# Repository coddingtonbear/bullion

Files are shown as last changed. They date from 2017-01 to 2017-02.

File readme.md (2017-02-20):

# USB & SPI Interface for FS9721-based Multimeter (Bullion)



Do you have a cheap Chinese multimeter using the FS9721 chipset and
want to add an easy-to-use USB interface to it?  Or, do you have an
arduino project in mind where you might want to collect measurements
from your multimeter?  This project can help you do both of those things.

## Compatible Multimeters

Any multimeter using the FS9721 chipset is compatible, but you may have
to adapt the hardware design herein if your multimeter does not have a
3.5mm stereo jack labeled "RS232".

Known-compatible multimeters include:

* **RECOMMENDED** [TekPower TP4000ZC](https://www.amazon.com/Tekpower-TP4000ZC-Interfaced-Multimeter-Computer/dp/B000OPDFLM)
    * Also available as the Digitek DT-4000ZC.
    * Includes a 3.5mm RS232 port.
* [Mastech V&A 18B](https://www.amazon.com/Manual-Ranging-Digital-Multimeter-Interface/dp/B000LQONYM)
    * Does have an external RS232 port, but it is not compatible with the
      hardware files you'll find herein.  You will have to improvise.
* [UNI-T UT60E](https://www.amazon.com/UNI-T-UT60E-Precise-Light-Weight/dp/B0152OJAWC)
    * Does have an external RS232 port, but it is not compatible with the
      hardware files you'll find herein.  You will have to improvise.

## Interfaces

### USB

* Baud Rate: 2400

When connected to your PC, the device will appear as an additional serial
port (may require installation of a driver for the CH340G USB UART
chip).

By default, the raw output from the Multimeter will be displayed
as new multimeter data is received in a way identical to that of what the
built-in serial port would output were you to connect it directly to your
computer, but you can select a variety of output formats using the below
commands.

#### Commands

Commands are sent in the format `COMMAND=VALUE` followed by a single
newline character.

* Command ``output``:
    * Value ``raw`` (*default*): Display raw bytes received from multimeter.
    * Value ``value``: Display actual value scaled to base unit.
    * Value ``displayed``: Display displayed value.  Note that this is
      not scaled to the base unit.  Use the ``unit`` command below to
      determine magnitude.
    * Value ``none``: Disable output.
* Command ``units``:
    * Value ``0`` (*default*): Do not print unit.
    * Value ``1``: Print unit.  If the value is not scaled to the base
      unit, this may include an SI magnitude prefix ('u', 'n, 'm', 'k', 'M').

**Note**: *Command output is not displayed until you press <ENTER>*

For example; to display units in the format they are displayed on the screen,
you could send the following two commands:

```
output=displayed
units=1
```

and you would, assuming you were measuring a voltage source, receive responses like:

```
1.244 mV
1.239 mV
```

But, if you wanted to output values scaled to their base unit so programs
consuming these values wouldn't need to worry about the SI magnitude, you
could instead send the following commands:

```
output=value
units=1
```

and you'd receive the following values:

```
0.001244 V
0.001239 V
```

You could even turn off unit display if you were not concerned about
identifying what mode the multimeter was in while the returned measurement
was taking place (note, though, that `units=0` is the default state, so
you need not send that command if you have not already enabled unit display):

```
output=value
units=0
```

and then you'd receive very easy-to-parse values:

```
0.001244
0.001239
```

### SPI

Every SPI transaction is a single 8-bit command ID, followed by a
32-bit response.

The following commands are implemented:

* `0x01`: Return multimeter measurement as IEEE 754 floating point value; this
  value is scaled to the appropriate base unit for the mode in which the
  multimeter is currently operating..
* `0x02`: Return multimeter display as IEEE 754 floating point value.
  Note that this value is not scaled to handle displayed SI magnitudes!
* `0x10`: Return current display flags as bits in this order:
  * 31:
  * 30: Sign
  * 29: Low Battery
  * 28: Hold
  * 27: Rel
  * 26: Beep
  * 25: Sign (?)
  * **24**: RS232
  * 23: AUTO
  * 22: 
  * 21: 
  * 20: M (mega)
  * 19: k (kilo)
  * 18: m (milli)
  * 17: n (nano)
  * **16**: µ (micro)
  * 15: C2C1 00 (?)
  * 14: C2C1 01 (?)
  * 13: C2C1 10 (?)
  * 12: C2C1 11 (?)
  * 11:
  * 10: Diode
  * 09: DC
  * **08**: AC
  * 07:
  * 06:
  * 05: %
  * 04: Hz
  * 03: V
  * 02: A
  * 01: F
  * 00: Ω

#### SPI Troubleshooting

The device itself operates as an SPI slave, and it's rather difficult to
keep up with fast SPI speeds with just a 12Mhz clock, so if you have unreliable
results, try slowing down your SPI bus speed -- it's not like you're
going to ever be able to get more than a few measurements/second
anyway given that the multimeter itself only measures 2-3x second.

#### Arduino Example

```c
#include <SPI.h>

#define MM_PIN 9

void setup() {
  digitalWrite(MM_PIN, HIGH);
  pinMode(MM_PIN, OUTPUT);
  pinMode(MISO, INPUT);
  pinMode(MOSI, OUTPUT);
  pinMode(SCK, OUTPUT);
  SPI.begin();
  SPI.beginTransaction(SPISettings(1000, MSBFIRST, SPI_MODE0));

  Serial.begin(9600);
}

void loop() {
  union {
      float measurement;
      unsigned char bytes[4];
  } floatMeasurement;

  digitalWrite(MM_PIN, LOW);

  // Let's get the current measurement
  SPI.transfer(0x01);
  for(uint8_t i = 0; i < 4; i++) {
    floatMeasurement.bytes[i] = SPI.transfer(i);
  }
  Serial.println(floatMeasurement.measurement, 7);
  digitalWrite(MM_PIN, HIGH);

  delay(500);

  // Now let's print the current flags
  digitalWrite(MM_PIN, LOW);
  SPI.transfer(0x10);
  for(uint8_t i = 0; i < 4; i++) {
    Serial.println(SPI.transfer(i), BIN);
  }
  digitalWrite(MM_PIN, HIGH);

  delay(3000);
}
```

## Hardware



Check out the `hardware` directory to find Kicad schematics and layout.  The
layout you'll find was designed for *homemade* *pcb* *fabrication* (note how 
big the vias are and the presence of "transit" vias for working around the
lack of through-hole plating), but it could be sent to your favorite PCB
boardhouse for manufacture if desired.

The following major components are used (see the schematic for details):

* ATMEGA328PB Microcontroller in the QFP package. A normal ATMEGA328P
  would work fine, too, but you will have to update a handful of SPI-related
  register and interrupt names to remove the extra zero (the -PB version
  has two SPI peripherals).
  Although the ATMEGA328PB is a little more capable than the ATMEGA328P
  these days, they are just a little cheaper; both are around 2.5 USD.
* CH340G USB-to-UART IC: You can buy these from Aliexpress or wherever
  for less than 0.50 USD.
* 12Mhz Crystal (SMD HC-49)
* A MicroUSB connector.
* A standard through-hole 3.5mm stereo connector.

Note that the design relies upon the CH340G chip sharing the
microcontroller's clock; you will want to set the `CKOUT=0` fuse
(generally titled "Clock output on PORTB0").

## Future Thoughts

There are lots of things about this project that I'd change if I were to
approach it again; those include:

* Making the primary serial interface I2C instead of SPI.
    * I2C provides a lot more flexibility for letting a device take
      extra time to perform slow operations via "clock stretching".  As
      this is currently designed, SPI is used, and the client device must
      be able to keep up with the clock speed set by the master or data
      will be lost.
    * With I2C, you can save a wire or two!
    * The downside is that we might have to expose a couple extra pins
      since the current header is used for both programming and the serial
      interface.  If I2C is added, either two additional header pins will
      need to be added, or maybe a multiplexer chip allowing two header
      pins to be shared individually between two different microcontroller
      pins.
* Orient the microcontroller at a 45˚ angle.  This should make routing a
  little less chaotic.
* Add reverse current protection!  Not having such protection was a little
  bit of an embarassing oversight.
* Use either a MicroUSB breakout board or a MiniUSB connector instead of
  the existing MicroUSB connector. Soldering that tiny connector onto
  a homemade PCB is very difficult -- the pin pitch of those connectors
  is 0.65mm; just a smidge below what my current process is able to
  resolve (~0.75mm) without needing to use a sharp knife to separate
  traces.
* Perhaps place devices on both sides of the board to save space?  It's
  not clear to me whether that would be worth it, but it could make the
  board a lot smaller.

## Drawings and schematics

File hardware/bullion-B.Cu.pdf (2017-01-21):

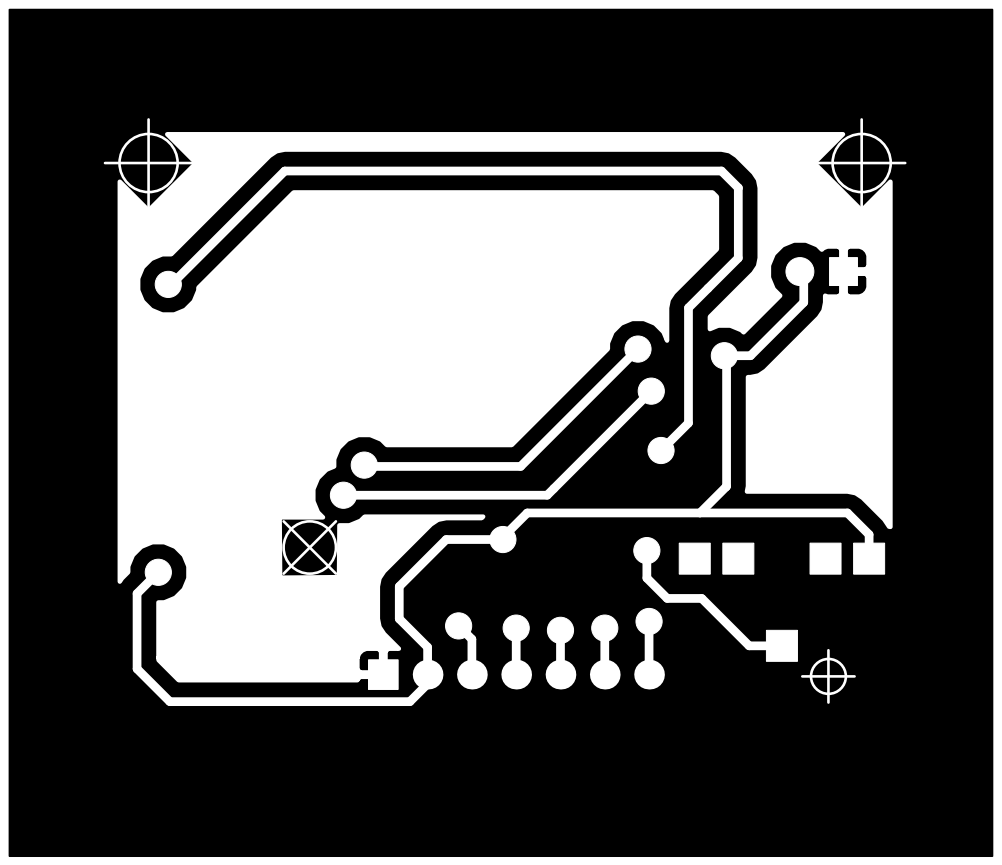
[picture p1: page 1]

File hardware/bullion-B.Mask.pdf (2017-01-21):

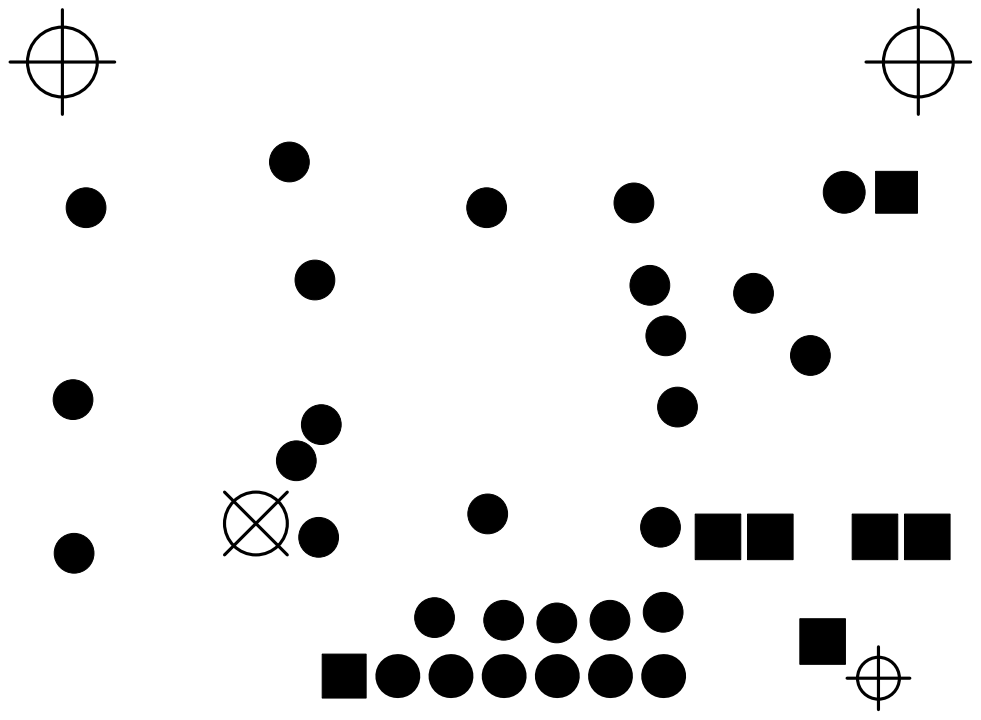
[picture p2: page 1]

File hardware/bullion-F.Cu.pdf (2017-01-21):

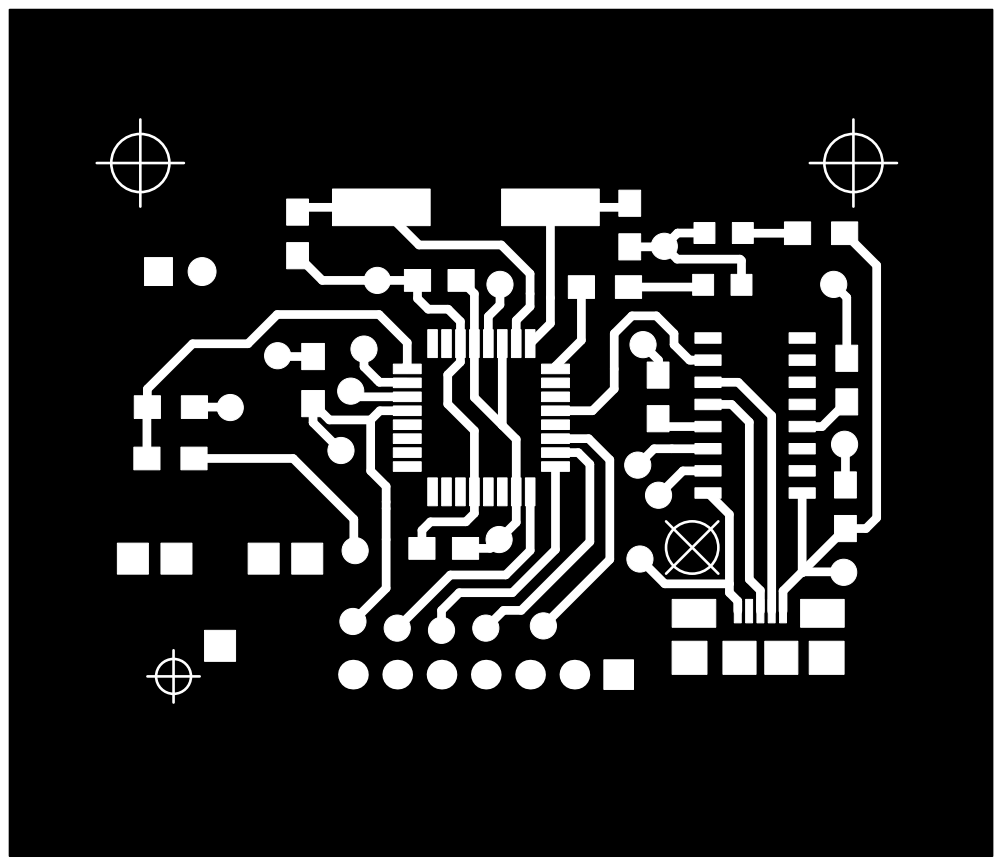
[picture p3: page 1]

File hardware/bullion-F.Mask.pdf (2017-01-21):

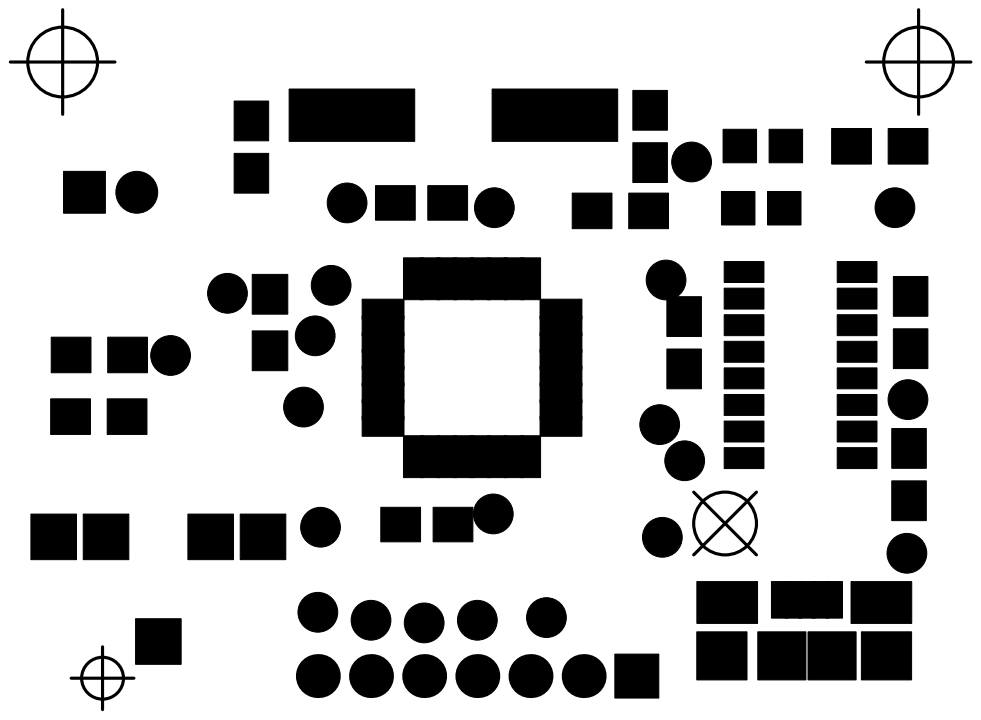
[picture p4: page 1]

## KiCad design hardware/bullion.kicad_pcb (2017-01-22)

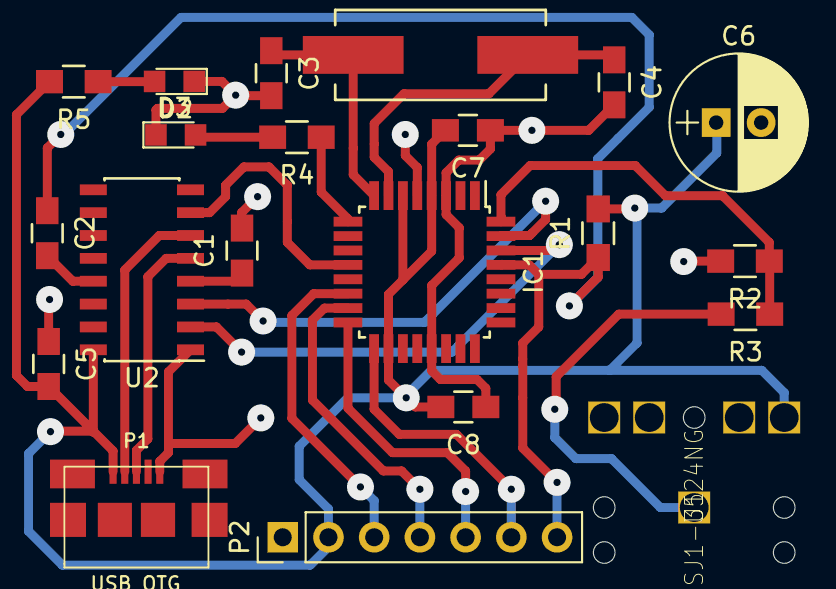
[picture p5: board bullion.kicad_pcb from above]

Board: 2 copper layers, 21 parts (0 on the bottom side), 21 nets.

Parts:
C1, C2, C5, C7, C8: 0.1u; C_0805_HandSoldering
C3, C4: 22p; C_0805_HandSoldering
C6: 47u; CP_Radial_D7.5mm_P2.50mm
D2: BLUE; LED_0805
D3: RED; LED_0805
IC1: ATMEGA328P-A; TQFP-32_7x7mm_Pitch0.8mm
P1: USB_OTG; MICRO-B_USB
P2: CONN_01X07; Pin_Header_Straight_1x07_Pitch2.54mm
R1: 10k; R_0805_HandSoldering
R2: 2.2k; R_0805_HandSoldering
R3: 220; R_0805_HandSoldering
R4: 82; R_0805_HandSoldering
R5: 4.7k; R_0805_HandSoldering
U1: SJ1-3524NG; PIN-4
U2: CH340G; SOIC-16_3.9x9.9mm_Pitch1.27mm
Y1: Crystal; Crystal_HC49-SD_SMD

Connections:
+5V: C5.2, C6.1, C7.2, C8.2, IC1.4, IC1.6, IC1.18, P1.1, P2.2, R1.2, R5.2, U1.2, U2.16
CLKOUT: IC1.12, U2.7
DTR: C2.2, U2.13
GND: C1.2, C3.2, C4.2, C5.1, C6.2, C7.1, C8.1, D2.1, D3.1, IC1.3, IC1.5, IC1.21, P1.5, P2.1, R2.2, U2.1
MM_TXD: IC1.32, R2.1, R3.1
unnamed: C1.1, U2.4
unnamed: C2.1, IC1.29, P2.7, R1.1
unnamed: C3.1, IC1.8, Y1.1
unnamed: C4.1, IC1.7, Y1.2
unnamed: D2.2, R4.2
unnamed: D3.2, R5.1
unnamed: IC1.9, R4.1
unnamed: IC1.14, P2.3
unnamed: IC1.15, P2.4
unnamed: IC1.16, P2.5
unnamed: IC1.17, P2.6
unnamed: P1.2, U2.6
unnamed: P1.3, U2.5
unnamed: R3.2, U1.1
RXD: IC1.30, U2.2
TXD: IC1.31, U2.3

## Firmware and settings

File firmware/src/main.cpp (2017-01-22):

#include "main.h"
#include "fs9721.h"

#define STATUS_LED 5
#define MM_RX 2
#define MM_TX 3

#define LED_LIGHT_TIME 10000

SoftwareSerial mm = SoftwareSerial(MM_RX, MM_TX, true);
FS9721 fs9721 = FS9721(&mm);

bool ledLit = false;
unsigned long ledLitUntil = 0;

SerialOutputType outputMode = RAW;
bool outputUnits = false;
String command = "";

byte currentValue[4];
byte currentDisplayedValue[4];
byte currentFlags[4];

byte spiCommand = 0;
byte* spiDataOut;
uint8_t spiDataPos = 0;
uint8_t spiDataLength = 0;


void setup() {
    mm.begin(2400);
    Serial.begin(2400);
    command.reserve(64);

    pinMode(SS, INPUT_PULLUP);
    pinMode(MISO, OUTPUT);
    SPCR0 |= _BV(SPE);
    SPCR0 |= _BV(SPIE);
}

ISR (SPI0_STC_vect)
{
    byte c = SPDR0;

    switch (spiCommand) {
        case 0x00: {
            spiCommand = c;
            spiDataPos = 1;

            switch (spiCommand) {
                case 0x01: {
                    spiDataOut = &currentValue[0];
                    break;
                }
                case 0x02: {
                    spiDataOut = &currentDisplayedValue[0];
                    break;
                }
                case 0x10: {
                    spiDataOut = &currentFlags[0];
                    break;
                }
                default: {
                    // Just to make sure that a value is set;
                    spiDataOut = &currentFlags[0];
                    spiCommand = 0;
                }
            }

            SPDR0 = spiDataOut[0];
            break;
        }
        default: {
            SPDR0 = spiDataOut[spiDataPos];
            spiDataPos++;
        }
    }
}

void flashStatusLed() {
    digitalWrite(STATUS_LED, HIGH);
    ledLitUntil = micros() + LED_LIGHT_TIME;
}

void updateStatusLed() {
    if(micros() > ledLitUntil) {
        digitalWrite(STATUS_LED, LOW);
    }
}

void readSerialData() {
    char byte = Serial.read();

    if(byte == '\n') {
        uint8_t idx = command.indexOf('=');
        if(idx == -1) {
            command = "";
            command.reserve(64);
            return;
        }
        String cmd = command.substring(0, idx);
        String value = command.substring(idx + 1);
        value.trim();
        cmd.trim();

        bool errorValue = false;
        bool errorCommand = false;
        command = "";
        command.reserve(64);

        Serial.print(cmd);
        Serial.print('=');
        Serial.println(value);

        if (cmd.compareTo("output") == 0) {
            if(value == "raw") {
                outputMode = RAW;
            } else if(value.compareTo("none") == 0) {
                outputMode = NONE;
            } else if(value.compareTo("value") == 0) {
                outputMode = VALUE;
            } else if(value.compareTo("displayed") == 0) {
                outputMode = DISPLAYED;
            } else {
                errorValue = true;
            }
        } else if(cmd.compareTo("units") == 0) {
            if(value == "1") {
                outputUnits = true;
            } else if(value == "0") {
                outputUnits = false;
            } else {
                errorValue = true;
            }
        } else {
            errorCommand = true;
        }
        if (errorCommand) {
            Serial.println("ERROR: INVALID COMMAND");
        } else if(errorValue) {
            Serial.println("ERROR: INVALID VALUE");
        } else {
            Serial.println("OK");
        }

    } else {
        command = command + byte;
    }
}

void writeMultimeterBytes() {
    switch(outputMode) {
    case RAW:
    {
        int bytes[14];
        fs9721.getBytes(bytes);
        for(uint8_t pos = 0; pos < 14; pos++) {
            Serial.write(bytes[pos]);
        }
        break;
    }
    case VALUE:
    {
        float value = fs9721.getValue();
        Serial.print(value, 10);
        if(outputUnits) {
            Serial.print(" ");
            Serial.println(fs9721.getUnit());
        } else {
            Serial.println("");
        }
        break;
    }
    case DISPLAYED:
    {
        float displayedValue = fs9721.getDisplayedValue();
        Serial.print(displayedValue, 4);
        if(outputUnits) {
            Serial.print(" ");
            Serial.println(fs9721.getDisplayedUnit());
        } else {
            Serial.println("");
        }
        break;
    }
    default:
        break;
    }
}

void updatePreparedValues() {
    union {
        float measurement;
        unsigned char bytes[4];
    } thing;

    thing.measurement = fs9721.getValue();
    for(int i = 0; i < 4; i++) {
        currentValue[i] = thing.bytes[i];
    }

    thing.measurement = fs9721.getDisplayedValue();
    for(int i = 0; i < 4; i++) {
        currentDisplayedValue[i] = thing.bytes[i];
    }

    fs9721_info* flags = fs9721.getFlags();
    for(int i = 0; i < 4; i++) {
        uint8_t flag = 0;
        switch(i) {
            case 0: {
                flag |= flags->is_sign << 6;
                flag |= flags->is_bat << 5;
                flag |= flags->is_hold << 4;
                flag |= flags->is_rel << 3;
                flag |= flags->is_beep << 2;
                flag |= flags->is_sign << 1;
                flag |= flags->is_rs232 << 0;
                break;
            }
            case 1: {
                flag |= flags->is_auto << 7;
                flag |= flags->is_mega << 4;
                flag |= flags->is_kilo << 3;
                flag |= flags->is_milli << 2;
                flag |= flags->is_nano << 1;
                flag |= flags->is_micro << 0;
                break;
            }
            case 2: {
                flag |= flags->is_c2c1_00 << 7;
                flag |= flags->is_c2c1_01 << 6;
                flag |= flags->is_c2c1_10 << 5;
                flag |= flags->is_c2c1_11 << 4;
                flag |= flags->is_diode << 2;
                flag |= flags->is_dc << 1;
                flag |= flags->is_ac << 0;
                break;
            }
            case 3: {
                flag |= flags->is_percent << 5;
                flag |= flags->is_hz << 4;
                flag |= flags->is_volt << 3;
                flag |= flags->is_ampere << 2;
                flag |= flags->is_farad << 1;
                flag |= flags->is_ohm << 0;
                break;
            }
        }
        currentFlags[i] = flag;
    }
}

void loop() {
    while(mm.available()) {
        if(fs9721.update()) {
            flashStatusLed();
            writeMultimeterBytes();
            updatePreparedValues();
        }
    }
    while(Serial.available()) {
        readSerialData();
    }
    updateStatusLed();

    if(spiCommand && digitalRead(SS)) {
        spiCommand = 0;
    }
}

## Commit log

2017-01-16 And so it begins...
    [bullion.kicad_pcb, bullion.sch]
2017-01-21 Adding LEDs; fixing RS232 connection.
    [bullion.kicad_pcb, bullion.sch]
2017-01-22 Updating hardware to latest revision; adding readme.
    [bullion.kicad_pcb, bullion.sch]
2017-01-22 Adding board rendering.
2017-01-22 Fixing board layout image.
2017-02-20 Adding schematic.
